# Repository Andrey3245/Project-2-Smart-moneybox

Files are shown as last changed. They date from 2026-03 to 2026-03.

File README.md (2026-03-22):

# Умная копилка

- [Описание проекта](#описание-проекта)
- [Принципиальная схема](#принципиальная-схема)
  - [Зарядный модуль](#зарядный-модуль)
  - [Повышающий преобразователь](#повышающий-преобразователь)
  - [Автономность](#автономность)
  - [Устранение помех](#устранение-помех)
- [Печатная плата в Altium Designer](#печатная-плата-в-altium-designer)
- [Готовое устройство](#готовое-устройство-на-печатной-плате)
- [Корпус](#корпус)
- [Демонстрация работы устройства](#демонстрация-работы-устройства)
- [Итог](#итог)

## Описание проекта


Проект создан в 2017 году как проводная версия. Его прообразом послужил проект от AlexGyver, который я взял за основу и впоследствии значительно переработал: напечатал новый корпус на 3D-принтере, переработал схему, развел печатную плату и изготовил её вручную

В основе лежит метод оптического прерывания. При прохождении монеты через луч инфракрасного светодиода она частично перекрывает излучение, направленное на фототранзистор. Чем меньше диаметр монеты, тем меньше перекрытие: 1 рубль дает минимальное падение напряжения на фототранзисторе, 5 рублей — максимальное.

Система записывает сигнал с привязкой ко времени пролета, получая зависимость падения напряжения от времени. Затем эта кривая сравнивается с калибровочными эталонами для каждого номинала, заранее сохраненными в памяти.

В процессе работы устройство подсчитывает количество монет каждого номинала и умеет выводить итоговый отчет.
  
## Принципиальная схема
схема

### Зарядный модуль
Зарядный модуль для аккумулятора 18650 реализован по классической схеме с использованием 3-х микросхем: 

- TP4056 — заряжает аккумулятор стабильным током до 1 А до достижения 4,2 В

- DW01A — контроллер защиты отслеживает напряжение на аккумуляторе и ток через нагрузку, обеспечивая защиту от переразряда ниже 2,4 В, перезаряда выше 4,3 В и перегрузки по току (КЗ)

- FS8205A - сдвоенный N-канальный MOSFET, который разрывает цепь между аккумулятором и схемой по сигналу от DW01A (при переразряде, перезаряде или КЗ), переходя в режим блокировки и требуя подключения зарядного устройства для выхода из этого режима.

Индикация процесса зарядки стандартная: красный светодиод горит во время зарядки, зеленый загорается по окончании.  

### Повышающий преобразователь
Для питания Arduino и дисплея используется повышающий DC-DC преобразователь на микросхеме MC34063. Входное напряжение: 3–4,2 В (аккумулятор 18650), выходное: 5 В.

Первоначальная схема:
Arduino питалась напрямую от аккумулятора, а повышающий преобразователь и дисплей включались отдельно по сигналу от Arduino через MOSFET. Главный недостаток: при снижении напряжения на аккумуляторе до 3,9 В происходило преждевременное отключение микроконтроллера, хотя аккумулятор был еще далеко не разряжен.

Итоговая схема:
Arduino запитывается от непрерывно работающего повышающего преобразователя MC34063. Это позволило стабилизировать напряжение на входе микроконтроллера на уровне 5 В, благодаря чему система сохраняет полную работоспособность даже при снижении напряжения на аккумуляторе до 3 В. Дисплей по-прежнему управляется отдельно по сигналу от Arduino через транзисторный ключ.

### Автономность
Однако стабилизация питания имела обратную сторону — рост энергопотребления:

- Активный режим: 124 мА

- Режим сна: 4 мА, из которых: 0,07 мА приходится на Arduino, 3,93 мА — собственное потребление преобразователя MC34063

Таким образом, в режиме сна 97% всего потребления приходится на микросхему MC34063 и лишь 3% — на микроконтроллер. Аккумулятора емкостью 2000–3000 мА·ч хватает примерно на 20 дней.

Для дальнейшего снижения энергопотребления необходима замена микросхемы преобразователя на более экономичную, например MT3608, у которой собственный ток намного ниже.

UPD: Ошибки, допущенные в данном проекте, стали очевидны лишь спустя месяц, когда я приступил к разработке «Метеостанции». Оптимизируя энергопотребление в новом устройстве (снижение частоты МК и порога BOD), я понял: это решение идеально подошло бы и для «Копилки».

Исходная схема, где Arduino во сне питалась через постоянно работающий повышающий преобразователь, оказалась неэффективной. Правильнее было запитать преобразователь через MOSFET (включая его только по необходимости), а Arduino подключить напрямую к аккумулятору. Благодаря сниженному порогу BOD микроконтроллер не отключался бы даже при падении напряжения до 2,7 В, а преобразователь просыпался бы только для вывода информации на дисплей.

Такая доработка могла бы увеличить автономность устройства до одного года.

### Устранение помех
Повышающий импульсный преобразователь на MC34063 создавал значительные помехи, из-за чего Arduino работала некорректно: система самопроизвольно засчитывала отсутствующие монеты.

Начальная версия (навесной монтаж): Для подавления помех достаточно было установить электролитический конденсатор 470 мкФ.

После перехода на печатную плату: Этой меры оказалось недостаточно. Для надежного подавления помех потребовался комплекс мер:

- Добавлен LC-фильтр с частотой среза 2,3 кГц

- Топология платы изменена — преобразователь максимально удален от Arduino и аналоговой части (фототранзистор)

- Разделение земель — аналоговая земля отделена от силовой

В результате устройство стало работать стабильно, а ослабление пульсаций составило 18,6 дБ, что соответствует снижению уровня помех в 8,5 раза по напряжению.  
Сравнение осциллограмм до и после применения фильтра приведено на рисунках ниже)





## Печатная плата в Altium Designer
top3

bottom

## Готовое устройство на печатной плате
Для обеспечения компактности печатной платы и гибкости размещения компонентов в корпусе устройства — аккумулятора, фототранзистора, ИК-светодиода, кнопки включения и дисплея — их подключение к основной плате реализовано через разъемы типа PLS

Плата изготовлена вручную с помощью фоторезистивного метода. Для изоляции токопроводящих дорожек на плату нанесена паяльная маска, сформированная методом УФ-экспонирования через фотошаблон.




## Корпус
3D-моделирование выполнено в SolidWorks, печать корпуса — из ABS-пластика. 

Особенности конструкции:
- Крепление: дисплей и аккумуляторный отсек зафиксированы винтами М3 через вплавляемые гайки, запрессованные в пластик корпуса
- Монтаж платы: ПП удерживается пластиковыми клипсами
- Компоновка: внутреннее пространство разделено перегородкой, изолирующей электронику от монет
- Доступ к монетам: задняя крышка скользит по направляющим, что позволяет легко и быстро извлекать содержимое
- Интерфейсы: разъем зарядки и светодиодная индикация выведены на левую грань корпуса

Хочу сказать отдельное спасибо Передовой инженерной школе «ЛЭТИ» и аспиранту кафедры ЭПУ Кушнаревой Олесе Андреевне за помощь и предоставленную возможность в реализации корпуса для проекта

## Демонстрация работы устройства
Конструкция и функционал — [на видео (Rutube)](https://rutube.ru/shorts/2335825f3e7b261264db152730252cfa/)
[Видео в ВК](https://vk.com/video339693071_456240567?list=ln-ZNQXKRs4tkY4rvlRGl)

## Итог
Проект «Копилка» прошел полноценный путь развития: от первого прототипа в DIY-корпусе с навесным монтажом до законченного устройства на печатной плате в индивидуальном корпусе, изготовленном с помощью 3D-печати.  


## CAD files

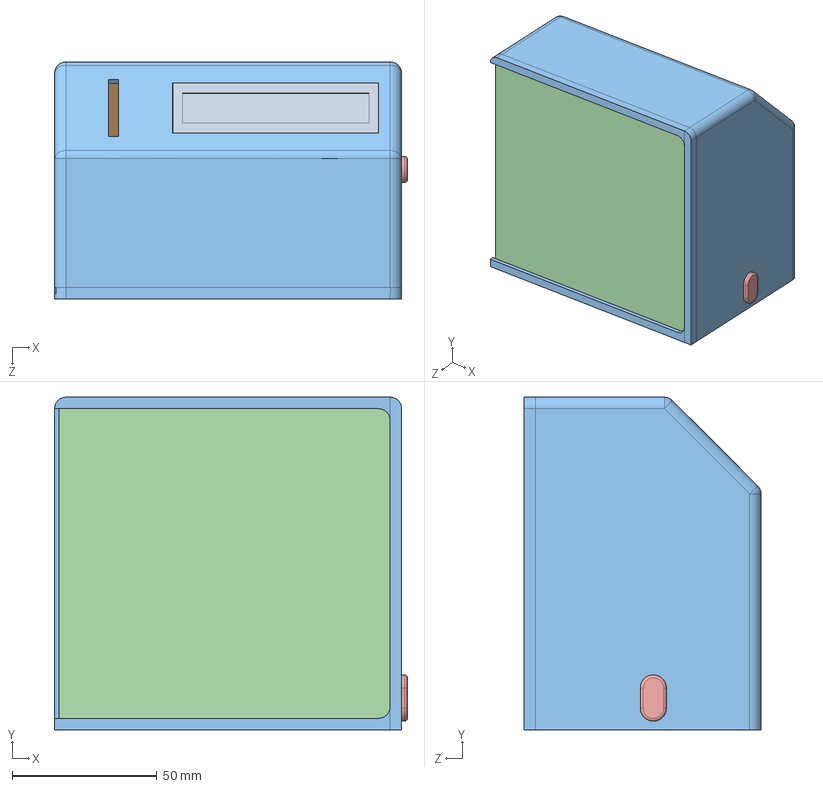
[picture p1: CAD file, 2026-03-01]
Assembly Solid Works/Сборка2.SLDASM
122.0 x 115.0 x 82.0 mm
корпус основной
монетоприемник
дисплей 1602
holderх18650
печатная плата
перегородка
разъем
задняя крышка
[M3-4.5]-Heat Set Inserts x 6
ГОСТ 17475-80 (алюминиевый сплав) x 6

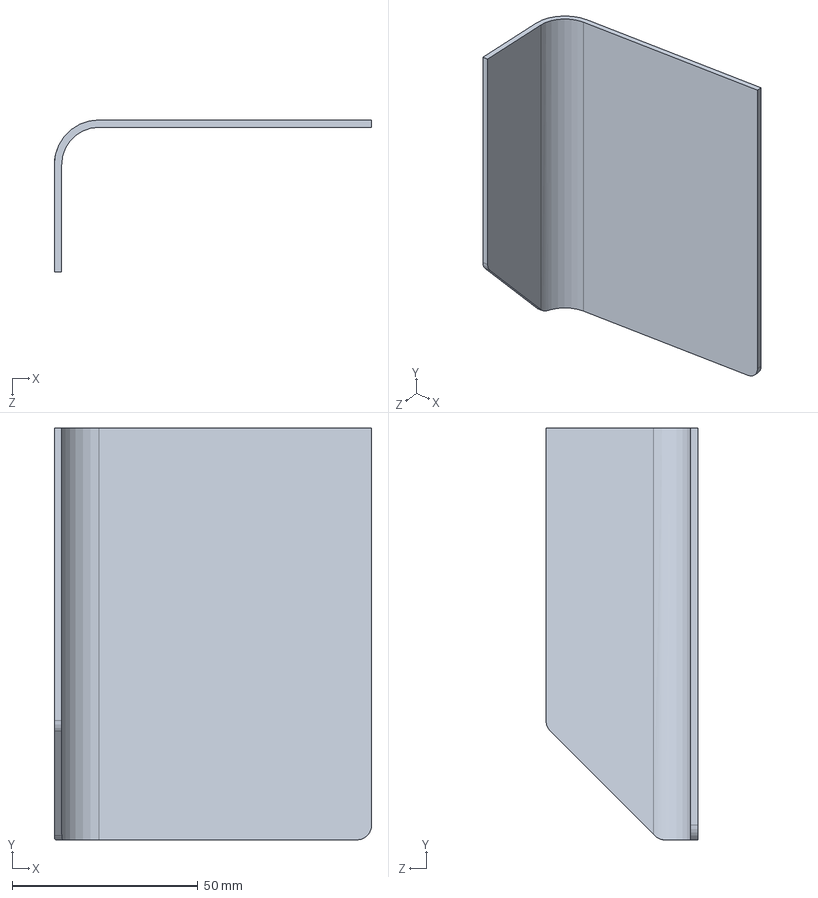
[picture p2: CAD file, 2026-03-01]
Assembly Solid Works/перегородка.SLDPRT
85.5 x 111.0 x 41.0 mm

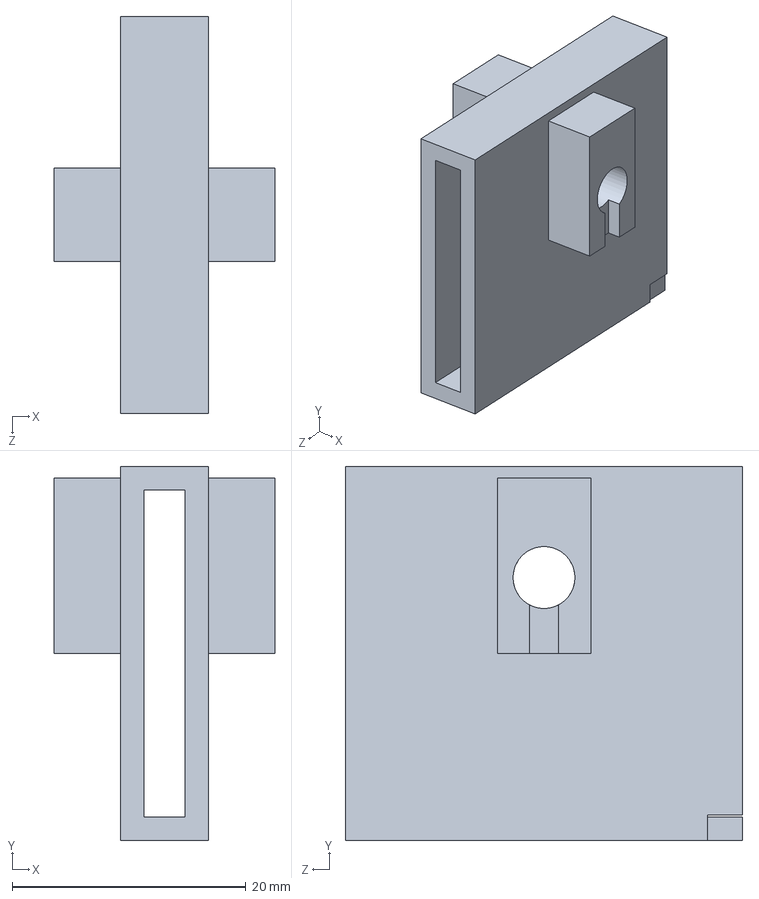
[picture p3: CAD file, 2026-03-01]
Assembly Solid Works/монетоприемник.SLDPRT
18.9 x 32.0 x 34.0 mm

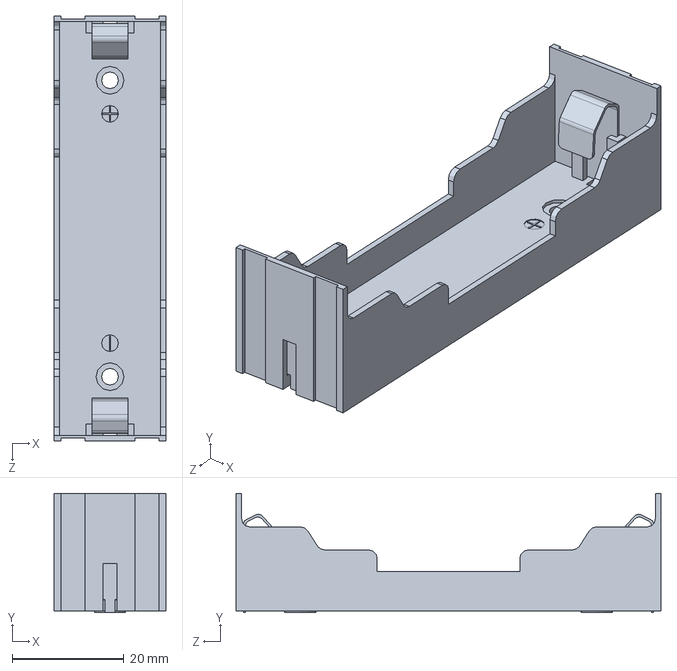
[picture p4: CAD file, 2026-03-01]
Assembly Solid Works/holderх18650.SLDPRT
20.0 x 21.3 x 76.0 mm

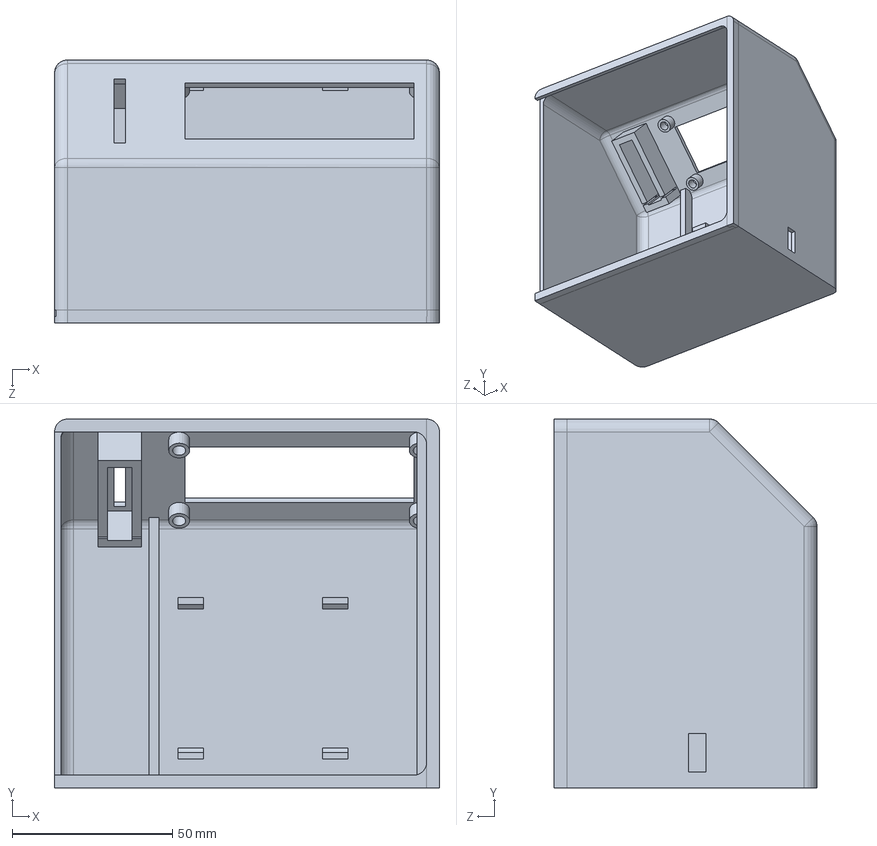
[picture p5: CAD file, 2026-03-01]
Assembly Solid Works/корпус основной.SLDPRT
120.0 x 115.0 x 82.0 mm

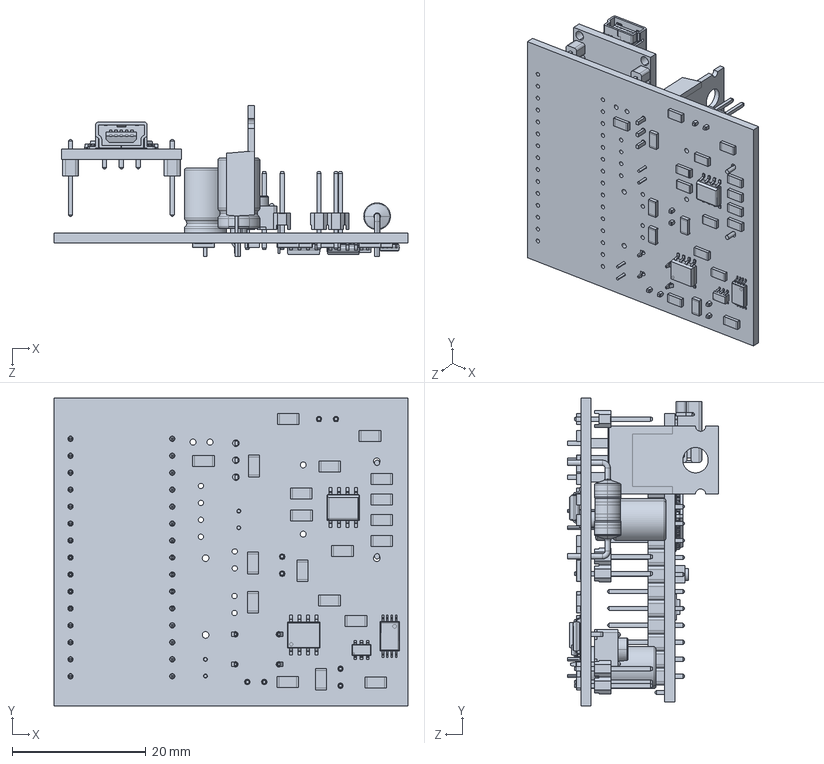
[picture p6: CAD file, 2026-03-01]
Assembly Solid Works/печатная плата.SLDPRT
53.0 x 46.1 x 22.6 mm

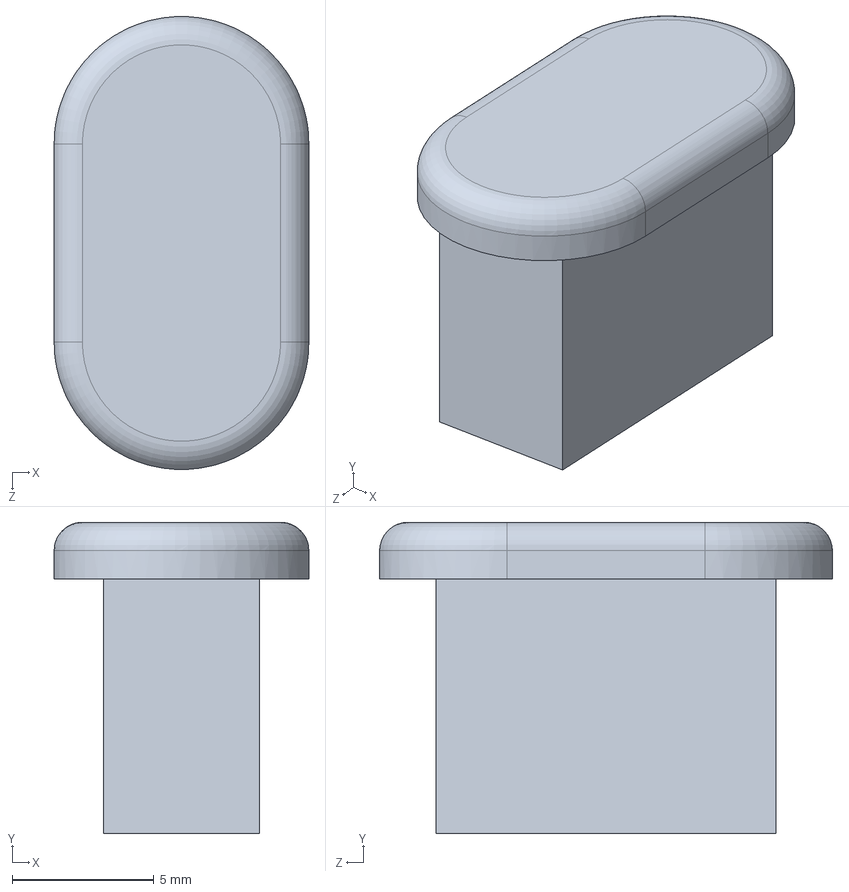
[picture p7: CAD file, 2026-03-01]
Assembly Solid Works/разъем.SLDPRT
9.00 x 11.0 x 16.0 mm

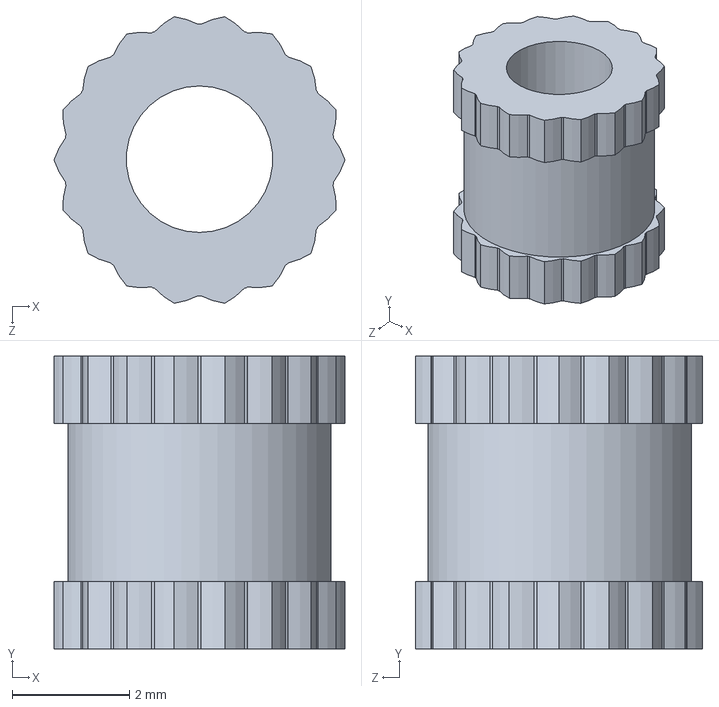
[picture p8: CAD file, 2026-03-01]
Assembly Solid Works/[M3-4.5]-Heat Set Inserts.SLDPRT
4.97 x 5.00 x 4.89 mm

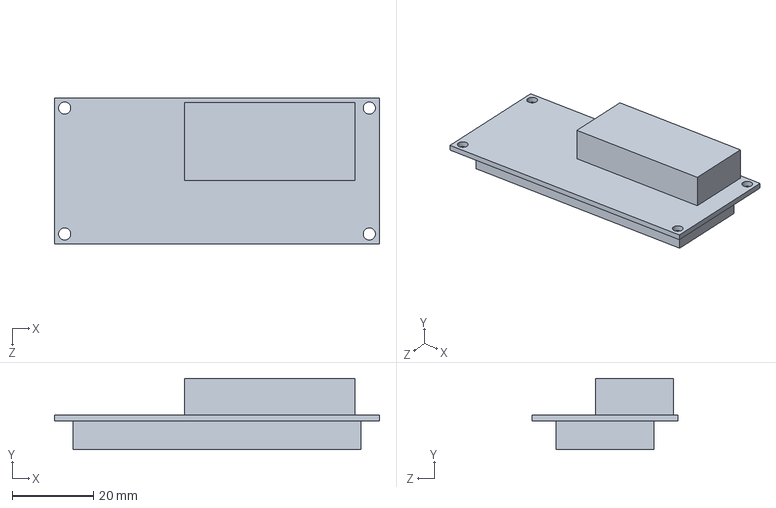
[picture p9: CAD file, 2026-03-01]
Assembly Solid Works/дисплей 1602.SLDPRT
80.0 x 17.5 x 36.0 mm

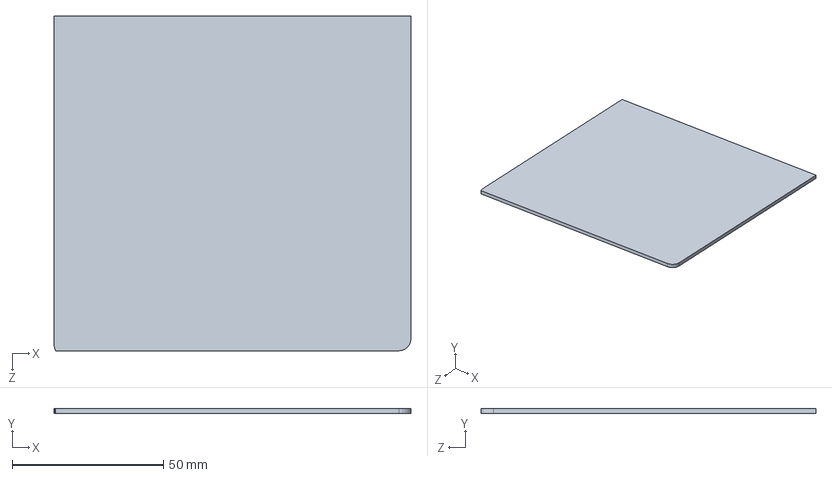
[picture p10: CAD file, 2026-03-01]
Assembly Solid Works/задняя крышка.SLDPRT
118.0 x 1.80 x 110.6 mm

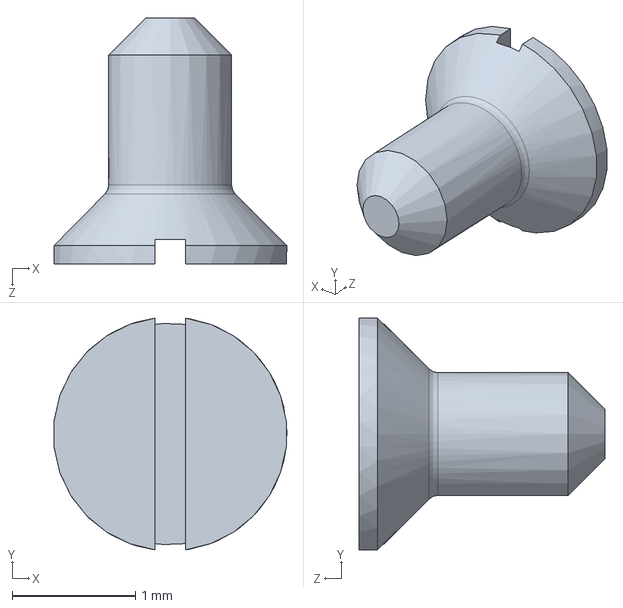
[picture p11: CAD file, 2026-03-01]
Assembly Solid Works/ГОСТ 17475-80 (алюминиевый сплав).SLDPRT
1.89 x 1.88 x 2.00 mm

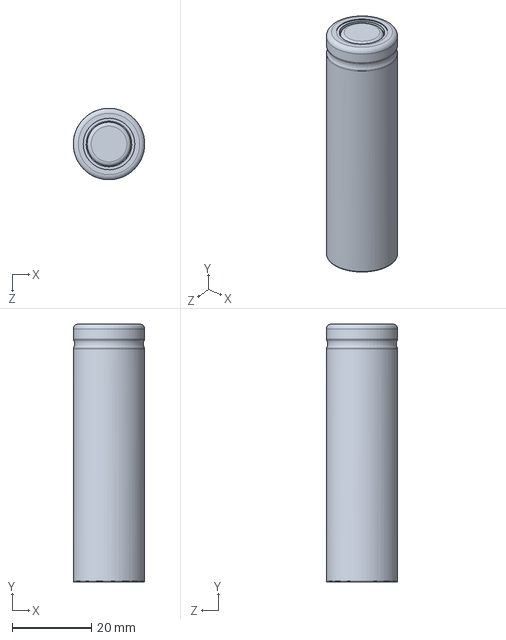
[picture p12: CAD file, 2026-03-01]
Assembly Solid Works/18650.SLDPRT
18.0 x 65.0 x 18.0 mm
